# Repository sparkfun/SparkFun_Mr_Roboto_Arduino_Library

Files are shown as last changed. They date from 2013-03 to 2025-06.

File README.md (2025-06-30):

Mr. Roboto Kit
========================

[Assembled Mr. Roboto Kit  
*Mr. Roboto Kit (KIT-11257)*](https://www.sparkfun.com/products/11257)

Mr. Roboto is an Arduino-compatible development board designed to be used as a teaching tool for Arduino programming. All of the surface mount components come pre-soldered so a few minutes of simple through-hole soldering is all it takes to get him up and running. After the kit is put together, the on board sensors, buzzer and LCD screen make an excellent platform for learning how to write code for physical computing.

Repository Contents
-------------------

* **/firmware** - Arduino example code
* **/hardware** - PCB design files (created with Eagle 6.1.0)

Product Versions
----------------

**[KIT-11257](https://www.sparkfun.com/products/11257) - Mr. Roboto Kit OEM packaging**  
The Mr. Roboto Kit in standard OEM packaging.

**[RTL-11384](https://www.sparkfun.com/products/11384) - Mr. Roboto Kit retail packaging**  
The Mr. Roboto Kit in a retail-ready plastic clam shell.

License Information
-------------------

All contents of this repository are released under [Creative Commons Share-alike 3.0](http://creativecommons.org/licenses/by-sa/3.0/).

Author
------

Jim Lindblom, [SparkFun Electronics](https://www.sparkfun.com)

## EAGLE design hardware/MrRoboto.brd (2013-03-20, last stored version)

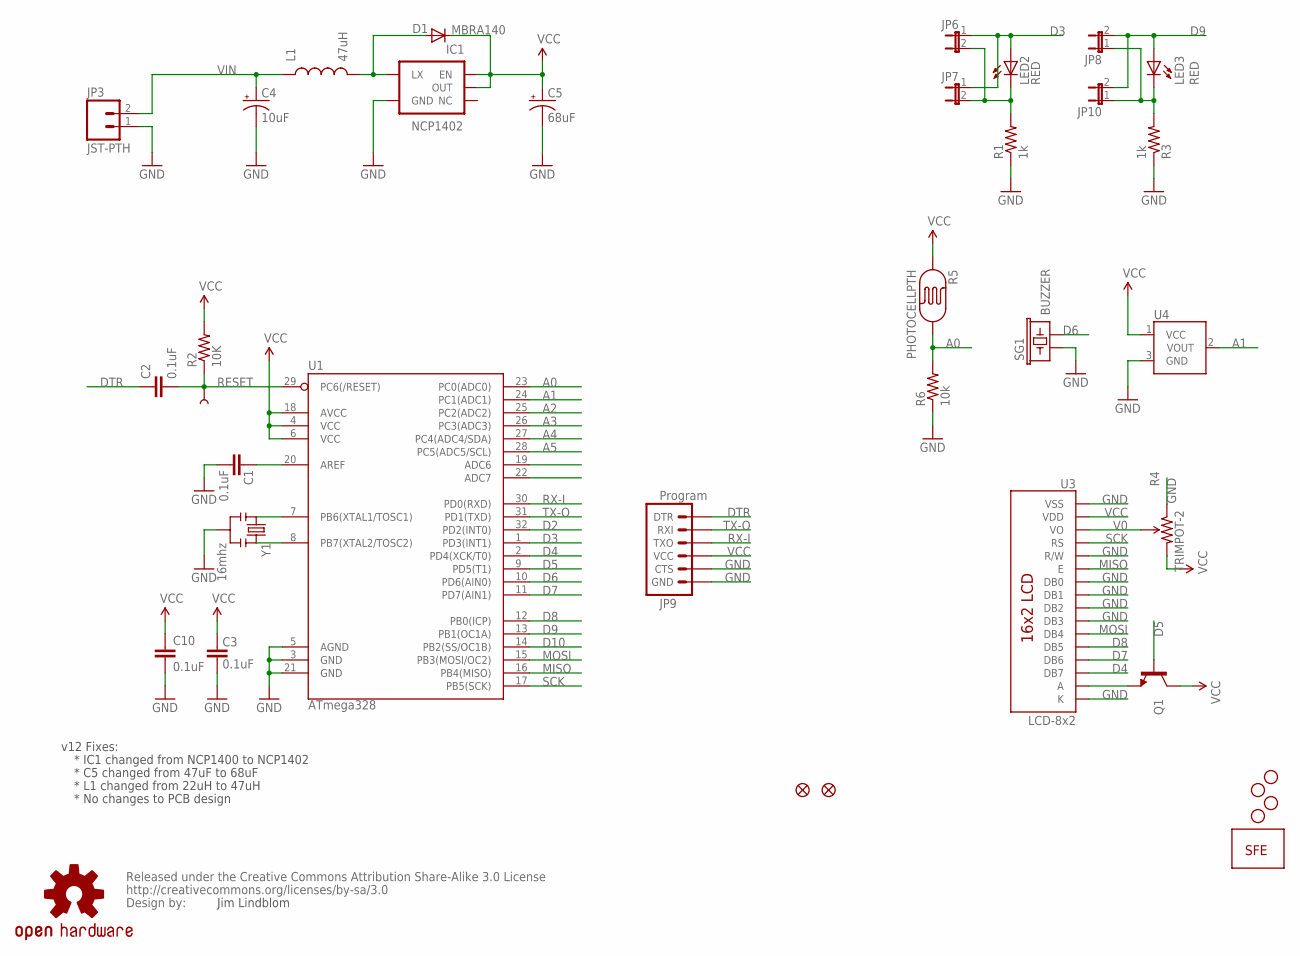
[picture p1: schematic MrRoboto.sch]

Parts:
C1, C2, C3, C10: 0.1uF; 0402-CAP
C4: 10uF; EIA3216
C5: 68uF; EIA3528
D1: MBRA140; SMA-DIODE
IC1: NCP1402; SOT23-5
JP1, JP2, JP4, JP5: Long, Plastic; STAND-OFF
JP3: JST-PTH; JST-2-PTH-KIT
JP6, JP7, JP8, JP10: JUMPER-2SMD-NO-NS; SJ_2S-NO-NS
JP9: Program; 1X06-KIT
JP11, JP12: FIDUCIAL1X2.5; FIDUCIAL-1X2.5
L1: 47uH; CR54
LED2, LED3: RED; LED5MM-KIT
Q1: TRANSISTOR_NPNSOT23; SOT23
R1, R3: 1k; AXIAL-0.3-KIT
R2: 10K; 0402-RES
R4: TRIMPOT-2; TRIMPOT_TC33
R5: PHOTOCELLPTH; PHOTOCELL-KIT
R6: 10k; 0402-RES
SG1: BUZZER; BUZZER-12MM-NS-KIT
TP1: TP; PAD.03X.05
U1: ATmega328; TQFP32-08
U3: LCD-8x2; LCD-8X2-KIT
U4: TMP36TO-92-KIT; TO-92-KIT
U$1: CREATIVE_COMMONS
U$2: OSHW-LOGOM; OSHW-LOGO-M
U$3: LOGO-SFENEW; SFE-NEW-WEBLOGO
Y1: 16mhz; RESONATOR-SMD

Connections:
A0: R5.2, R6.2, U1.23 (PC0(ADC0))
A1: U1.24 (PC1(ADC1)), U4.2 (VOUT)
A2: U1.25 (PC2(ADC2))
A3: U1.26 (PC3(ADC3))
A4: U1.27 (PC4(ADC4/SDA))
A5: U1.28 (PC5(ADC5/SCL))
AREF: C1.2, U1.20 (AREF)
D2: U1.32 (PD2(INT0))
D3: JP6.1, JP7.1, LED2.A, U1.1 (PD3(INT1))
D4: U1.2 (PD4(XCK/T0)), U3.14 (DB7)
D5: Q1.1 (B), U1.9 (PD5(T1))
D6: SG1.- (2), U1.10 (PD6(AIN0))
D7: U1.11 (PD7(AIN1)), U3.13 (DB6)
D8: U1.12 (PB0(ICP)), U3.12 (DB5)
D9: JP8.2, JP10.2, LED3.A, U1.13 (PB1(OC1A))
D10: U1.14 (PB2(SS/OC1B))
DTR: C2.1, JP9.1 (DTR)
GND: C1.1, C3.1, C4.C (-), C5.C (-), C10.2, IC1.4 (GND), JP3.1, JP9.5 (CTS), JP9.6 (GND), R1.P$1 (1), R3.P$1 (1), R4.1 (CCW), R6.1, SG1.+ (1), U1.3 (GND), U1.5 (AGND), U1.21 (GND), U3.1 (VSS), U3.5 (R/W), U3.7 (DB0), U3.8 (DB1), U3.9 (DB2), U3.10 (DB3), U3.16 (K), U4.3 (GND), Y1.2
MISO: U1.16 (PB4(MISO)), U3.6 (E)
MOSI: U1.15 (PB3(MOSI/OC2)), U3.11 (DB4)
unnamed: D1.A, IC1.5 (LX), L1.P$2 (2)
unnamed: Q1.2 (E), U3.15 (A)
unnamed: U1.7 (PB6(XTAL1/TOSC1)), Y1.1
unnamed: JP8.1, JP10.1, LED3.K (C), R3.P$2 (2)
unnamed: U1.8 (PB7(XTAL2/TOSC2)), Y1.3
unnamed: JP6.2, JP7.2, LED2.K (C), R1.P$2 (2)
RESET: C2.2, R2.1, TP1.P$1, U1.29 (PC6(/RESET))
RX-I: JP9.3 (TXO), U1.30 (PD0(RXD))
SCK: U1.17 (PB5(SCK)), U3.4 (RS)
TX-O: JP9.2 (RXI), U1.31 (PD1(TXD))
V0: R4.2 (WIPER), U3.3 (VO)
VCC: C3.2, C5.A (+), C10.1, D1.C, IC1.1 (EN), IC1.2 (OUT), JP9.4 (VCC), Q1.3 (C), R2.2, R4.3 (CW), R5.1, U1.4 (VCC), U1.6 (VCC), U1.18 (AVCC), U3.2 (VDD), U4.1 (VCC)
VIN: C4.A (+), JP3.2, L1.P$1 (1)

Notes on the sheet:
Jim Lindblom
v12 Fixes:
* IC1 changed from NCP1400 to NCP1402
* C5 changed from 47uF to 68uF
* L1 changed from 22uH to 47uH
* No changes to PCB design

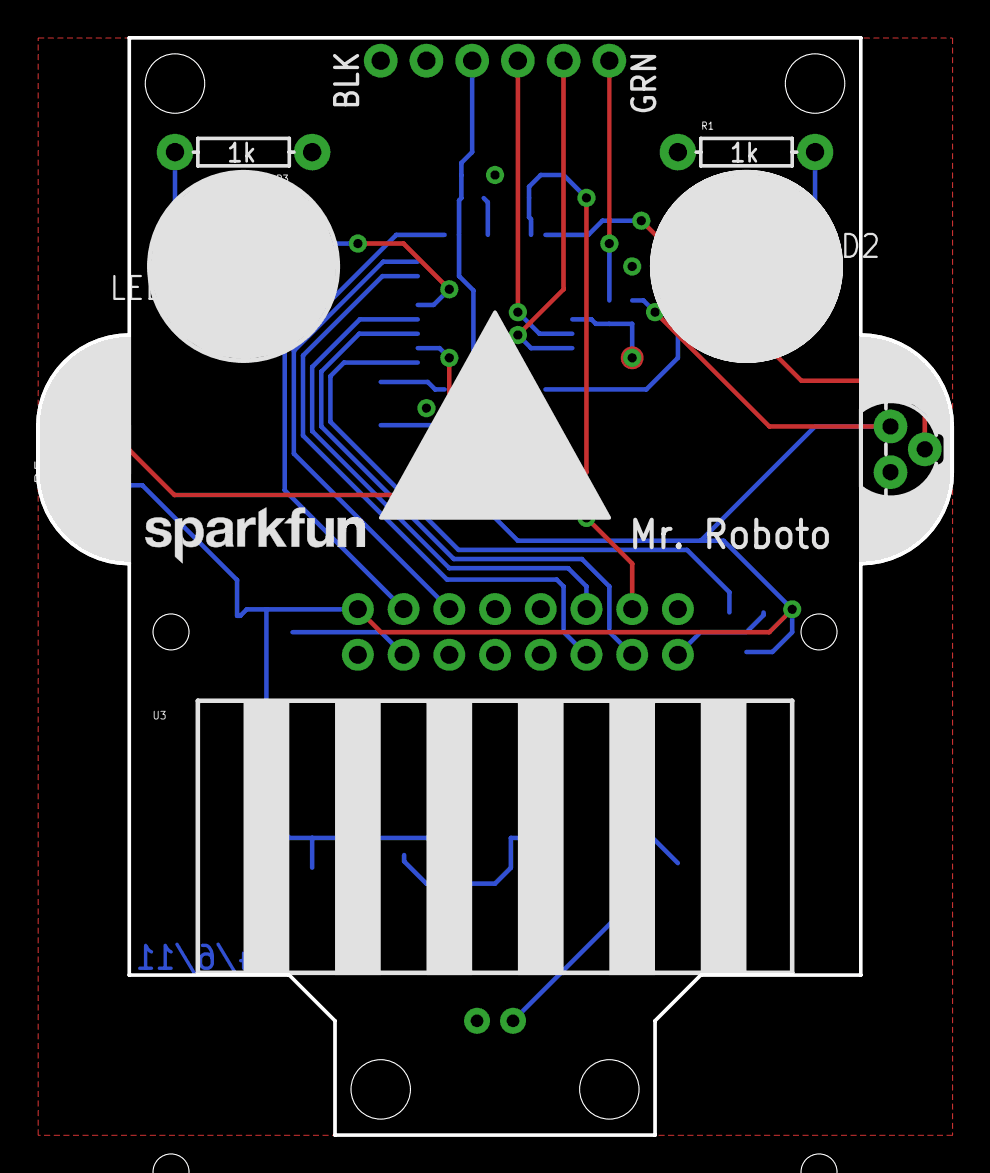
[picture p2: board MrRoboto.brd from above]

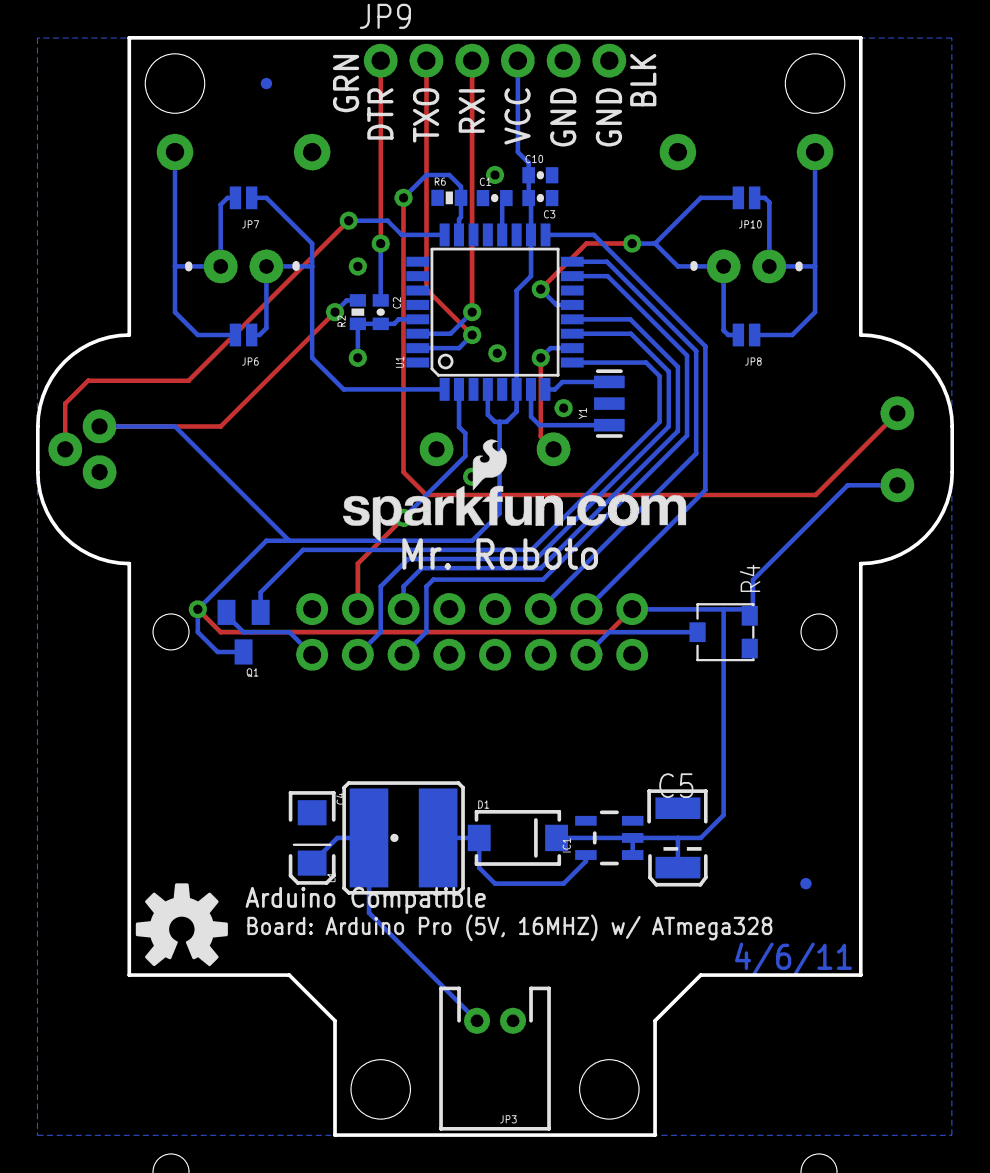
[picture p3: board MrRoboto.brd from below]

Board: 2 copper layers, 50.8 x 61.0 mm, 40 parts (25 on the bottom side), 27 nets.

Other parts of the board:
U$11: LOGO-SFENW2; SFE-NEW-WEB

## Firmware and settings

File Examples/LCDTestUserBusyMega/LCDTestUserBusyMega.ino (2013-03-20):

#include <LiquidCrystal.h>
#include <Streaming.h>

// Try to exercise everything in LiquidCrystal for test purposes--:  You should be able to modify the first 4 lines
// of code to test different options and swap LCD boards (with contrast potentiometers attached directly) by plugging them directly 
// into the row of digital sockets on the Mega opposite the USB socket. Be careful about current draw on the backlight pins!!
//Arduino can only power these if current draw is <= 40 mAmps  
uint8_t nRows = 4;      //number of rows on LCD
uint8_t nColumns =16;   //number of columns
uint8_t rw =47;         //255 if rw is connected vs 47 (or 49 for the 24x2) in the examples below; it should be pulled to GND if not controlled by the interface.
LiquidCrystal lcd(49,45, 35,33,31,29,&checkBusyFlag);  //there are multiple versions of this commented below; paste 'em in
                                        //this is kind of interesting: the LIquidCrystal object is created and init/begin is run
                                        //out here before setup(); before the board has power on the Mega!!! We need another begin to really
                                        //start the board later.


//======for an LCD with a single HD44780 type chip and 16 pin interface (eg 16x2 20x2 16x4 20x4) 4 data pinshttp://healthriskappraisal.org/LiquidCrystal440.zip

//Alternate interfaces to test for 2x16,4x20,4x16:
//LiquidCrystal lcd(49,47,45, 35,33,31,29);              // rs,rw,en, 4 data pins remember to set rw = 255 above
//LiquidCrystal lcd(49,47,45, 43,41,39,37, 35,33,31,29); // rs,rw,en 8 data pins remember to set rw = 255 above
//LiquidCrystal lcd(49,45, 35,33,31,29);                 // rs,en, 4 data pins  remember to set rw = 47 above
//LiquidCrystal lcd(49,45, 43,41,39,37, 35,33,31,29);    // rs,en 8 data pins  remember to set rw = 47 above
//LiquidCrystal lcd(49,45, 35,33,31,29,&checkBusyFlag);
//alternate interfaces to test for 4x40:
//LiquidCrystal lcd(48,47,46,52,  41,40,39,38); rs,rw,en1,en2,  4 data lines  set rw to 255 I don't see any way to eliminate rw and include en2 with fcn overloading.
//LiquidCrystal lcd(48,255,46,52,   41,40,39,38); rs,rw,en1,en2,  4 data lines  set rw to 47 but this trick should let me use a grounded RW and skip the checkLcdBusyFlag if I want.
//LiquidCrystal lcd(48,255,46,52,  41,40,39,38,&checkBusyFlag);

//Teensy++ stuff:
//LiquidCrystal lcd(1,2,3, 8,9,10,11);              // rs,rw,en, 4 data pins remember to set rw = 255 above
//LiquidCrystal lcd(1,3, 8,9,10,11,&checkBusyFlag);
//LiquidCrystal lcd(1,2,3, 4,5,6,7, 8,9,10,11); // rs,rw,en 8 data pins remember to set rw = 255 above
/*LiquidCrystal lcd(1,2,3, 8,9,10,11,&checkBusyFlag); 
#define set_data_pins_to_read DDRE&=~0x3,DDRC&=~0X3   //data pins 8-11 on TEENSY++
#define set_data_pins_to_write DDRE|=0x3,DDRC|=0X3    // D5,D4,D3,D2
#define set_EN_high PORTD |= 0b00001000    //port B3 pin 11
#define set_EN_low PORTD &= ~(1<<3)
#define set_EN2_high PORTD |= (1<<3)    //port D3  PIN3
#define set_EN2_low PORTD &= ~(1<<3)
#define set_RW_high PORTD |= (1<<2)
#define set_RW_low PORTD &= ~(1<<2)    //port D2 pin2
#define set_RS_high PORTD |= (1<<1)    //port D1  pin 1
#define set_RS_low PORTD &= ~(1<<1)
#define read_busy PINC & (1<<1)        //portD2, pin 2

    BACKLIGHT = 12;    // pin 27 will control the backlight  //before I solder pins in, I check current on the backlight
    BACKLTGND = 13;    // PIN 25 will be set LOW to provide a Gnd for the backlight
    POWER5V = 27;      // we will set this HIGH to provide power on pin 2 of the LCD
    GNDMain = 255;      // next to pin 53 (in the pin "55" position) is a GND--pin 1 of the LCD goes there 
*/
// Connections this assumes we attached a potentiometer  across LCD pins 1,2 and 3 with a standard 16 pin straight interface
//            and then plugged the LCD into the distal row of digital pins on a Mega
//            with the LCD extending away from the mega board:
//  this frees up the PWM pins for other uses. 
// rs (LCD pin 4) to Arduino pin 49
// rw (LCD pin 5) to Arduino pin 47
// enable (LCD pin 6) to Arduino pin 45
// LCD pin 15 to Arduino pin 27
// LCD pins d4, d5, d6, d7 to Arduino pins 35,33,31,29
//Arduino pins 51,43,41,39,37,23 are unused and hard to get at--you could interpose something like a stackable header between
//    the used pins and the LCD; then you could access the unused pins

//=====for a 4x40 LCD with 2 HD44780 type chips and 17 pin interface in 2 rows of 9; the pins are not arranged for
//     use with a breadboard, although you could solder a female socket onto the LCD board and use wires inserted 
//     female sockets or (as I did) to solder in stackable headers so that you can use the breadboard but
//     also can plug it into the 2 rows of digital sockets on the Mega.
//   LCD     Mega    Signal
//    18            Gnd        Backlight draws 480 mAmps!
//    17            +5V           
//    16      (53)    not used
//    15      52      En2 -- enable the 2nd HD44780 chip which controls the bottom 2 rows of the display
//    14      51*     +5V
//    13      50*     Gnd
//    12      --      Contrast resistor to Gnd
//    11      48      RS
//    10      47*     RW  -- could be strapped to Gnd 
//     9      46      En1 -- enable the 1st HD44780 which controls the top 2 rows
//    5-8    42-45*   Data 0-3 not used in 4 bit modes
//    1-4    38-41    Data 4-7
//This mode for the 4x40 is not working now://LiquidCrystal lcd(48,47,46,52,  45,44,43,42, 41,40,39,38); // rs,rw,en1,en2,  8 data lines  remember to set rw =255
//=========================================
//alternate versions to test for 2x24:  I have not seen this one actually work.
//LiquidCrystal lcd(50,49,48, 47,46,45,44, 43,42,41,40); // rs,rw,en 8 data pins remember to set rw = 255 above
//LiquidCrystal lcd(50,49,48,  43,42,41,40);            // rs,rw,en 4 data pins remember to set rw = 255 above
//LiquidCrystal lcd(50,48, 47,46,45,44, 43,42,41,40);   // rs,en 8 data pins remember to set rw = 49 above  -- these interfaces generally have unreliable initialization
//LiquidCrystal lcd(50,48, 43,42,41,40);                // rs,en 4 data pins remember to set rw = 49 above  -- these interfaces generally have unreliable initialization

//====2x24 LCD also has a non standard pinout and pins are numbered in the opposite direction:
//     1      53       Gnd
//     2      52        +5V
//     3      --        Contrast
//     4      50        RS
//     5      49        RW
//     6      48        EN
//    7-10    44-47    Data 0-3 not used in 4 bit mode
//    11-14   40-43    Data 4-7
//    15      --      Backlight +5v 147 mAmps!
//    16      --      Backlight Gnd
/* this would work for the 16x4 lined up over the Arduino:
#define set_data_pins_to_read DDRL &= ~0b01010101;   //data pins 42,44,46,48 on Arduino Mega
#define set_data_pins_to_write DDRL |= 0b01010101;
#define set_EN_high PORTC |= 0x20;    //port C bit 5
#define set_EN_low PORTC &= ~0x20;
#define set_RW_low PORTC &= ~0x80;    //port C bit 7
#define set_RW_high PORTC |= 0x80;
#define set_RS_high PORTA |= 0x40;    //port A bit 6
#define set_RS_low PORTA &= ~0x40;
#define read_busy PINL & 0x40;
*/

//this is for my standard position away from the Arduino:  Tested.

#define set_data_pins_to_read DDRC&=~0b01010100,DDRA&=~0x80;   //data pins 35,33,31,29 on Arduino Mega
#define set_data_pins_to_write DDRC|=0b01010100,DDRA|=0x80;    // C2,C4,C6,A7
#define set_EN_high PORTL |= 0b00010000;    //port L4 pin45
#define set_EN_low PORTL &= ~(1<<4);
#define set_EN2_high PORTL |= (1<<4);    //portL4
#define set_EN2_low PORTL &= ~(1<<4);
#define set_RW_high PORTL |= (1<<2);
#define set_RW_low PORTL &= ~(1<<2);    //port L bit 2 pin47
#define set_RS_high PORTL |= (1<<0);    //port L bit 0  pin 49
#define set_RS_low PORTL &= ~(1<<0);
#define read_busy PINA & (1<<7);         //port A7  pin29   This is the last pin number you specify to LiquidCrystal
/*
//This is for 40x4 Tested
#define set_data_pins_to_read DDRG&=~0b00000111,DDRD&=~0x80;   //data pins 41,40,39,38 on Arduino Mega
#define set_data_pins_to_write DDRG|=0b00000111,DDRD|=0x80;    // G0,G1,G2,D7
#define set_EN_high PORTL |= 0b00001000;    //port L3 pin46
#define set_EN_low PORTL &= ~(1<<3);
#define set_EN2_high PORTB |= (1<<1);    //portB1 pin 52
#define set_EN2_low PORTB &= ~(1<<1);
#define set_RW_high PORTL |= (1<<2);
#define set_RW_low PORTL &= ~(1<<2);    //port L bit 2 pin47
#define set_RS_high PORTL |= (1<<1);    //port L bit 1  pin 48
#define set_RS_low PORTL &= ~(1<<1);
#define read_busy PIND & (1<<7);         //port D7  pin38   This is the last pin number you specify to LiquidCrystal

/*
//LiquidCrystal lcd(12,11, 5,4,3,2,&checkBusyFlag); The is the example configuration from the Arduino tutorial for LiquidCrystal BUT hook RW to pin 10
#define set_data_pins_to_read DDRD&=~0b00111100;   //data pins 5,4,3,2 on Arduino 168,328
#define set_data_pins_to_write DDRD|=0b00111100;    // D5,D4,D3,D2
#define set_EN_high PORTB |= 0b00001000;    //port B3 pin 11
#define set_EN_low PORTB &= ~(1<<3);
#define set_EN2_high PORTB |= (1<<3);    //port B3 pin 11
#define set_EN2_low PORTB &= ~(1<<3);
#define set_RW_high PORTB |= (1<<2);
#define set_RW_low PORTB &= ~(1<<2);    //port B bit 2 pin10
#define set_RS_high PORTB |= (1<<4);    //port B bit 4  pin 12
#define set_RS_low PORTB &= ~(1<<4);
#define read_busy PIND & (1<<2);        //portD2, pin 2

#define set_data_pins_to_read pinMode(2,INPUT);pinMode(5,INPUT);pinMode(4,INPUT);pinMode(3,INPUT);   //data pins 5,4,3,2 
#define set_data_pins_to_write pinMode(2,OUTPUT);pinMode(5,OUTPUT);pinMode(4,OUTPUT);pinMode(3,OUTPUT); // digitalWrite etc gives some board independence
#define set_EN_high digitalWrite(11,HIGH);    //port B3 pin 11
#define set_EN_low digitalWrite(11,LOW);
#define set_EN2_high digitalWrite(11,HIGH);    //port B3 pin 11
#define set_EN2_low digitalWrite(11,LOW);
#define set_RW_high digitalWrite(10,HIGH);
#define set_RW_low digitalWrite(10,LOW);    //port B bit 2 pin10
#define set_RS_high digitalWrite(12,HIGH);    //port B bit 4  pin 12
#define set_RS_low digitalWrite(12,LOW);
#define read_busy digitalRead(2);        //portD2, pin 2
*/
void checkBusyFlag(int8_t chip) {
 uint8_t busy; // = 0x04;
 set_data_pins_to_read;
 set_RW_high;             //RW to read
 set_RS_low;
 if (chip == 0) {  //the if and else can be eliminated if only one hd44780 chip
 do {
   set_EN_high;
   delayMicroseconds(1);
   busy = read_busy;    // read busy flag
   set_EN_low;
   delayMicroseconds(1);
   set_EN_high; 
   delayMicroseconds(1);  //pulse the second nibble--discard it;
   set_EN_low; 
 }while (busy);
} else {
   do {
   set_EN2_high;
   delayMicroseconds(1);
   busy = read_busy;    // read busy flag
   set_EN2_low;
   delayMicroseconds(1);
   set_EN2_high; 
   delayMicroseconds(1);  //pulse the second nibble--discard it;
   set_EN2_low;
 } while (busy);
}
 set_data_pins_to_write; // data pins to write
 set_RW_low;              //RW to write
 set_RS_high;
}

byte BACKLIGHT, BACKLTGND, POWER5V, GNDMain;


void setup(void) {
        pinMode(13,OUTPUT);
        pinMode(12,OUTPUT);
        pinMode(11,OUTPUT);

	// set some digital pins to high and low to provide LCD with power and gnd:
	//             most of them: 2x16,4x20 4x16
    BACKLIGHT = 27;    // pin 27 will control the backlight  //before I solder pins in, I check current on the backlight
    BACKLTGND = 25;    // PIN 25 will be set LOW to provide a Gnd for the backlight
    POWER5V = 53;      // we will set this HIGH to provide power on pin 2 of the LCD
    GNDMain = 255;      // next to pin 53 (in the pin "55" position) is a GND--pin 1 of the LCD goes there 
	
	if ((nColumns == 40) && (nRows ==4)) {     //4x40
		BACKLIGHT = 255;    // Digital IO pins cannot control the backlight   for the 4x40 double HD44780 LCD  draws 480 mAmps !!
		BACKLTGND = 255;    //Arduino is limited to 40 mAmps
		POWER5V = 51;      // we will set this HIGH to provide power on pin 2 of the LCD
		GNDMain = 50; 
	}
	if ((nRows ==2) && (nColumns ==24) ) {  //2x24
		BACKLIGHT = 255;    //    the 2x24  draws 147 mAmps !!
		BACKLTGND = 255;    // 
		POWER5V = 53;      // we will set this HIGH to provide power on pin 2 of the LCD
		GNDMain = 52; 
	}
	pinMode(34,OUTPUT);
	pinMode(POWER5V, OUTPUT);          //We're using a digital out as a 5V power source for the LCD
	digitalWrite(POWER5V, HIGH);
	if (BACKLIGHT != 255) {
		pinMode(BACKLIGHT, OUTPUT);        //set 255 if you need to wire backlight to gnd bo high current draw
		digitalWrite(BACKLIGHT, HIGH);     // turn backlight on. Replace 'HIGH' with 'LOW' to turn it off.
		pinMode(BACKLTGND, OUTPUT);        //We're using a digital out as a GND for the backlight
		digitalWrite(BACKLTGND,LOW);
	}
	if (GNDMain != 255) {
		pinMode (GNDMain, OUTPUT);
		digitalWrite(GNDMain, LOW);

	}
	if (rw != 255) {
		pinMode(rw,OUTPUT);
		digitalWrite(rw,LOW);
	}

	randomSeed(analogRead(0));      //read unconnected pin to seed random number generator

	lcd.begin(nColumns,nRows);

}

void loop(void) {                     //this runs the LCD with the interface selected above through a fairly comprehensive series of tests

	lcd.clear();
	lcd.setCursor((nColumns>>1)-2,0);
	lcd.print( (int)lcd.numcols);
	lcd.print(",");
	lcd.print( (int)lcd.numlines);
	delay(1000);

// cursor tests--see if cursor correctly turned off as we leave second chip, mainly
        lcd.clear();
        lcd.noCursor();
        int i=0;
        while (i<nRows*2) {
        lcd(0,i%nRows)<<"no cursor"<<i;
        i++;
        delay(500);
        }
        delay(1000);
        
        lcd.clear();
        lcd.cursor();
        i=0;
        while (i<nRows*2) {
        lcd(0,i%nRows)<<"cursor"<<i;
        i++;
        delay(500);
        }
        delay(1000);
        lcd.noCursor();
        
        lcd.clear();
        lcd.blink();
        i=0;
        while (i<nRows*2) {
        lcd(0,i%nRows)<<"blink"<<i;
        i++;
        delay(500);
        }
        delay(1000);
        lcd.noBlink();
        
        lcd.clear();
        lcd.cursor();
        lcd.blink();
        i=0;
        while (i<nRows*2) {
        lcd(0,i%nRows)<<"c+b"<<i;
        i++;
        delay(500);
        }
        delay(1000);
        lcd.noCursor();
        lcd.noBlink();        
//end cursor test 1

// cursor tests--see if cursor correctly turned off as we leave second chip, mainly
        lcd.clear();
        lcd.noCursor();
        i=0;
        while (i<nRows*2) {
        lcd(0,i%nRows)<<"no cursor2"<<i;
        lcd.noDisplay();
        lcd.display();
        i++;
        delay(500);
        }
        delay(1000);
        
        lcd.clear();
        lcd.cursor();
        i=0;
        while (i<nRows*2) {
        lcd(0,i%nRows)<<"cursor2"<<i;
        lcd.noDisplay();
        lcd.display();
        i++;
        delay(500);
        }
        delay(1000);
        lcd.noCursor();
        
        lcd.clear();
        lcd.blink();
        i=0;
        while (i<nRows*2) {
        lcd(0,i%nRows)<<"blink2"<<i;
        lcd.noDisplay();
        lcd.display();
        i++;
        delay(500);
        }
        delay(1000);
        lcd.noBlink();
        
        lcd.clear();
        lcd.cursor();
        lcd.blink();
        i=0;
        while (i<nRows*2) {
        lcd(0,i%nRows)<<"c+b2"<<i;
        lcd.noDisplay();
        lcd.display();
        i++;
        delay(500);
        }
        delay(1000);
        lcd.noCursor();
        lcd.noBlink();        
//end cursor test  2

	//mark the corners
	lcd.setCursor(0,0);
	lcd.print('1');
	lcd.setCursor(nColumns-1,nRows-1);
	lcd.print('4');
	lcd.setCursor(0,nRows-1);
	lcd.print('3');
	lcd.setCursor(nColumns-1,0);
	lcd.print('2');
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

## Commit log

2013-03-20 Initial commit of hardware and readme
    [MrRoboto.brd, MrRoboto.sch]
2015-04-24 fixing things
    [MrRoboto.brd, MrRoboto.sch]

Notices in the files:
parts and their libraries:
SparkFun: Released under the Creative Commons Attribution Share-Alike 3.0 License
